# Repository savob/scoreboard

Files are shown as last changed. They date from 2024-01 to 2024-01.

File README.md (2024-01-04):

# Tools 102 Scoreboard

Scoreboard I made for the Tools 102 workshop in 2019. The goal was to bring in some electronics for people to learn with rather than just the usual mechanical stuff done. To that end I wanted to help build an electric countdown system based around an Arduino Nano which would show the time and keep track of score.

# Hardware

For this project I made the main board and a friend did the auxiliary detector board, both were designed to make the most of the back layer since these boards were going to be milled on campus, not etched in a factory. Thus there would be no plated through holes so keeping everything on the back made soldering and connections easier.

The boards were originally designed in EAGLE, but have since been converted to KiCad 7.0.10.

# Software

The code focused on the display function, and was all written in the Arduino IDE 1.8.13.

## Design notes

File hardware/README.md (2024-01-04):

# Hardware

Both these boards were made in EAGLE, but are now in KiCad (7.0.10) format. 

`detector` was meant to pickup a ball passing over a switch and make a single pulse using a 555 timer in monostable mode. A friend made this board.

`timeboard` was meant to be the main board for the system which would actually keep track of the score and display information like time remaining on the display for players to see.

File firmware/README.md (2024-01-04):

# Firmware

The firmware here is for the main board and ran on an Arduino Nano programmed using the Arduino IDE, version 1.8.13 when I wrote this.

Although this was meant to show the time remaining and ring the buzzer at completion, I only ended up focusing in on the display functionality since I really wanted to get the seven-segment to work nicely without any flickering as it was multiplexed digit by digit. I managed this in the second version by using hardware registers in the ATmega to control the outputs rather than the repeated and time-consuming `digitalWrite()` calls.

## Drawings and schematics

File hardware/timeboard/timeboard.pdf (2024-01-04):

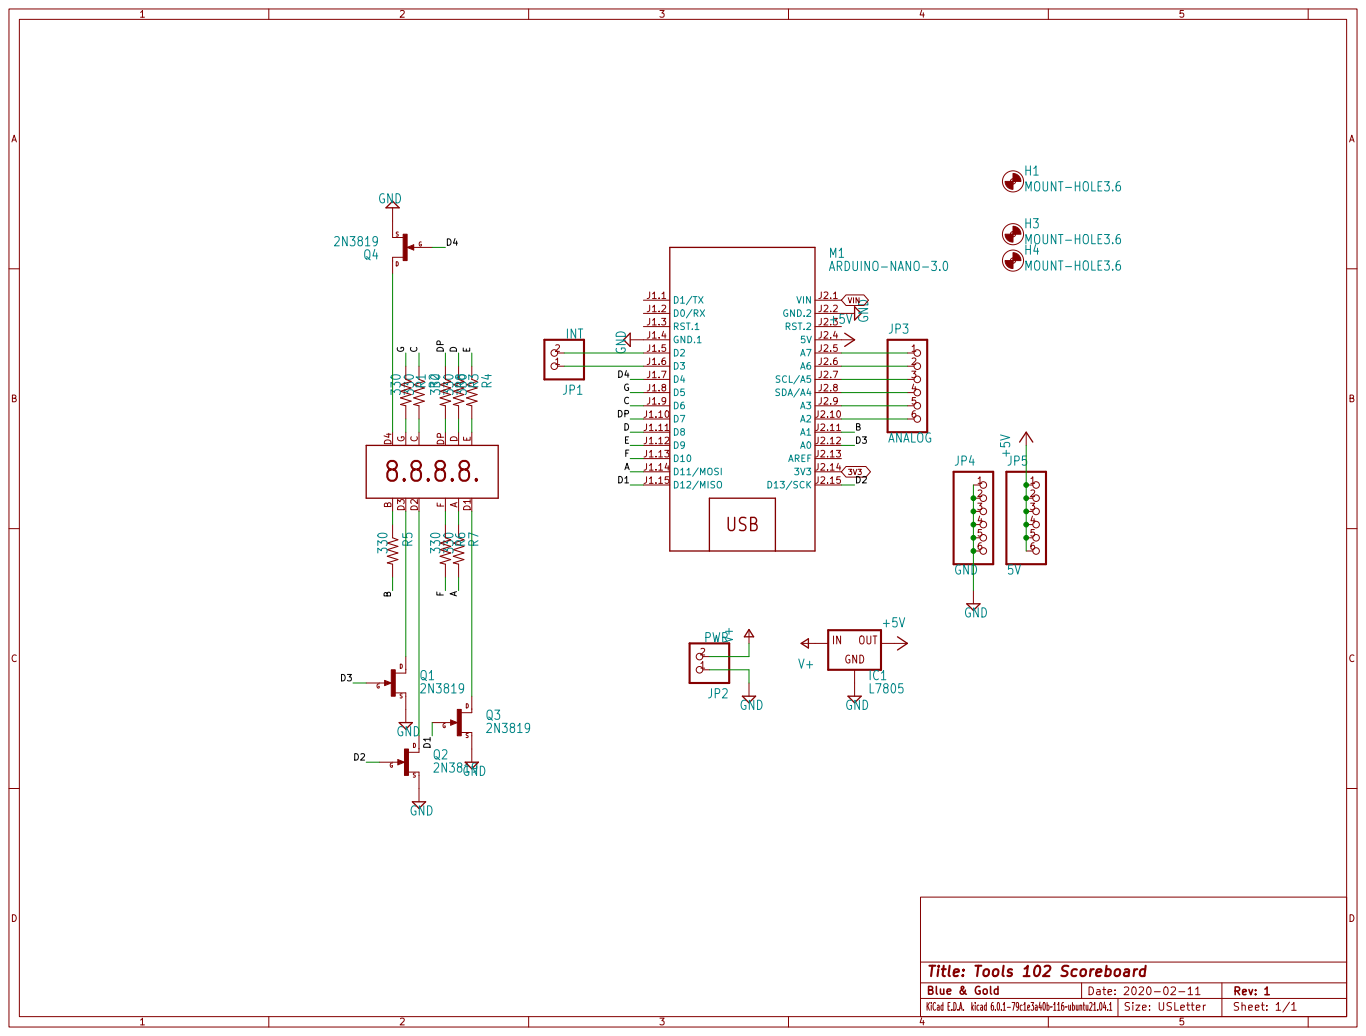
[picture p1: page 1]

Blue & Gold KiCad E.D.A. kicad 6.0.1-79c1e3a40b~116~ubuntu21.04.1 USB

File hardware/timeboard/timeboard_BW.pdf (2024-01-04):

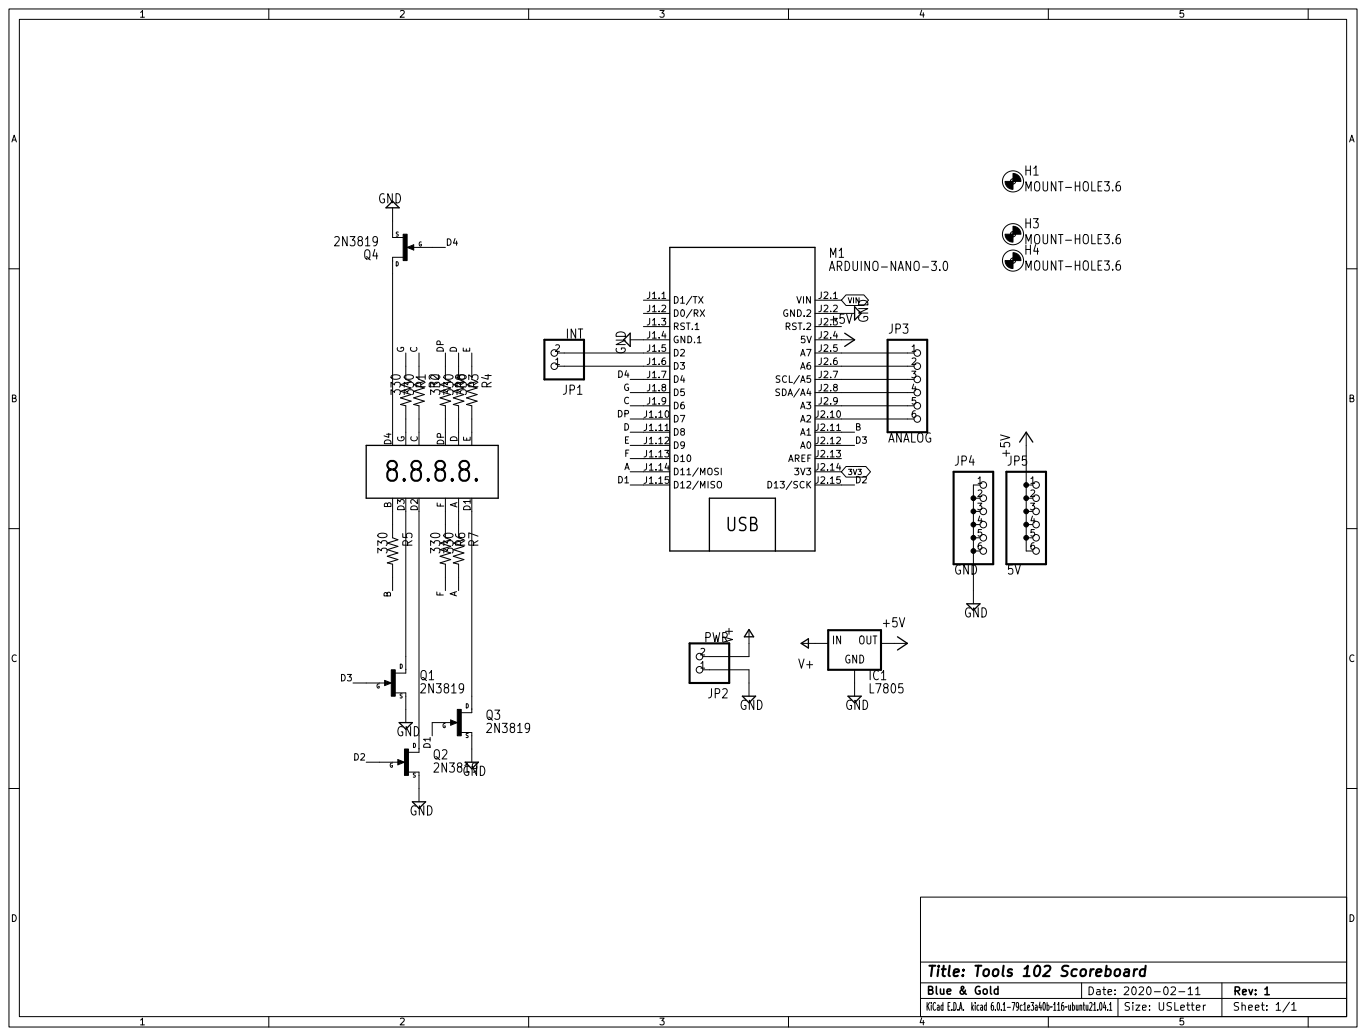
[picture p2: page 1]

Blue & Gold KiCad E.D.A. kicad 6.0.1-79c1e3a40b~116~ubuntu21.04.1 USB

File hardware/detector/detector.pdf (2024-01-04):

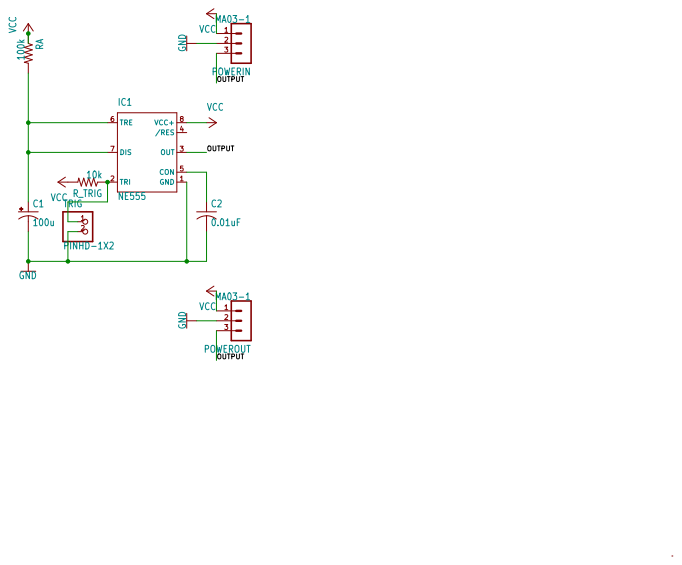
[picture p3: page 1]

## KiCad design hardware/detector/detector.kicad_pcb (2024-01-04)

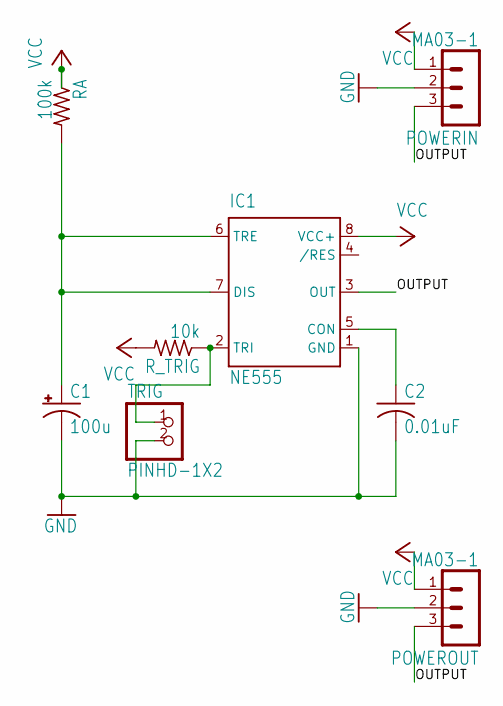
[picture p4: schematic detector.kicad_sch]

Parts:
C1: 100u; E3,5-8
C2: 0.01uF; C050-024X044
IC1: NE555; DIL-08
POWERIN: MA03-1
POWEROUT: MA03-1
RA: 100k; 0207_12
R_TRIG: 10k; 0207_12
TRIG: PINHD-1X2; 1X02

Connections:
GND: C1.-, C2.2, IC1.1 (GND), POWERIN.2, POWEROUT.2, TRIG.2
unnamed: C1.+, IC1.6 (TRE), IC1.7 (DIS), RA.2
unnamed: C2.1, IC1.5 (CON)
unnamed: IC1.2 (TRI), R_TRIG.1, TRIG.1
OUTPUT: IC1.3 (OUT), POWERIN.3, POWEROUT.3
VCC: IC1.8 (VCC+), POWERIN.1, POWEROUT.1, RA.1, R_TRIG.2

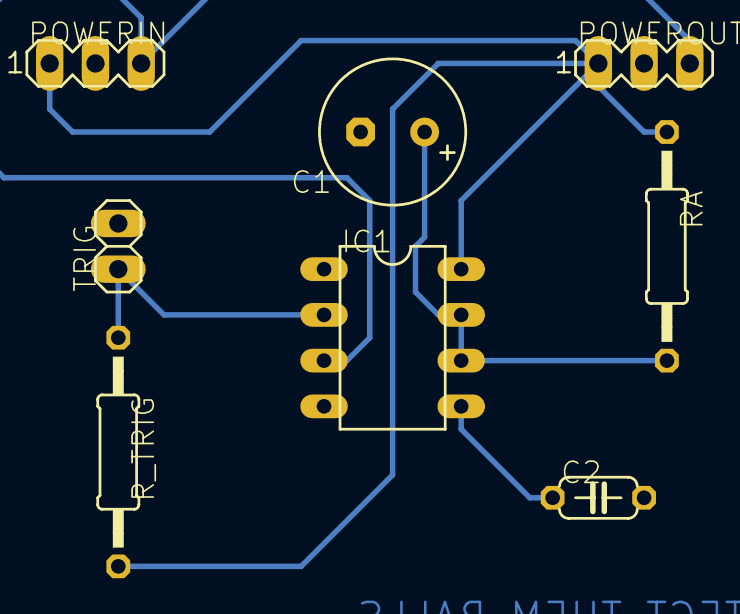
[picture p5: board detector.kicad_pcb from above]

Board: 2 copper layers, 12 parts (0 on the bottom side), 6 nets.

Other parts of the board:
@HOLE0, @HOLE1, @HOLE2, @HOLE3: (no value)

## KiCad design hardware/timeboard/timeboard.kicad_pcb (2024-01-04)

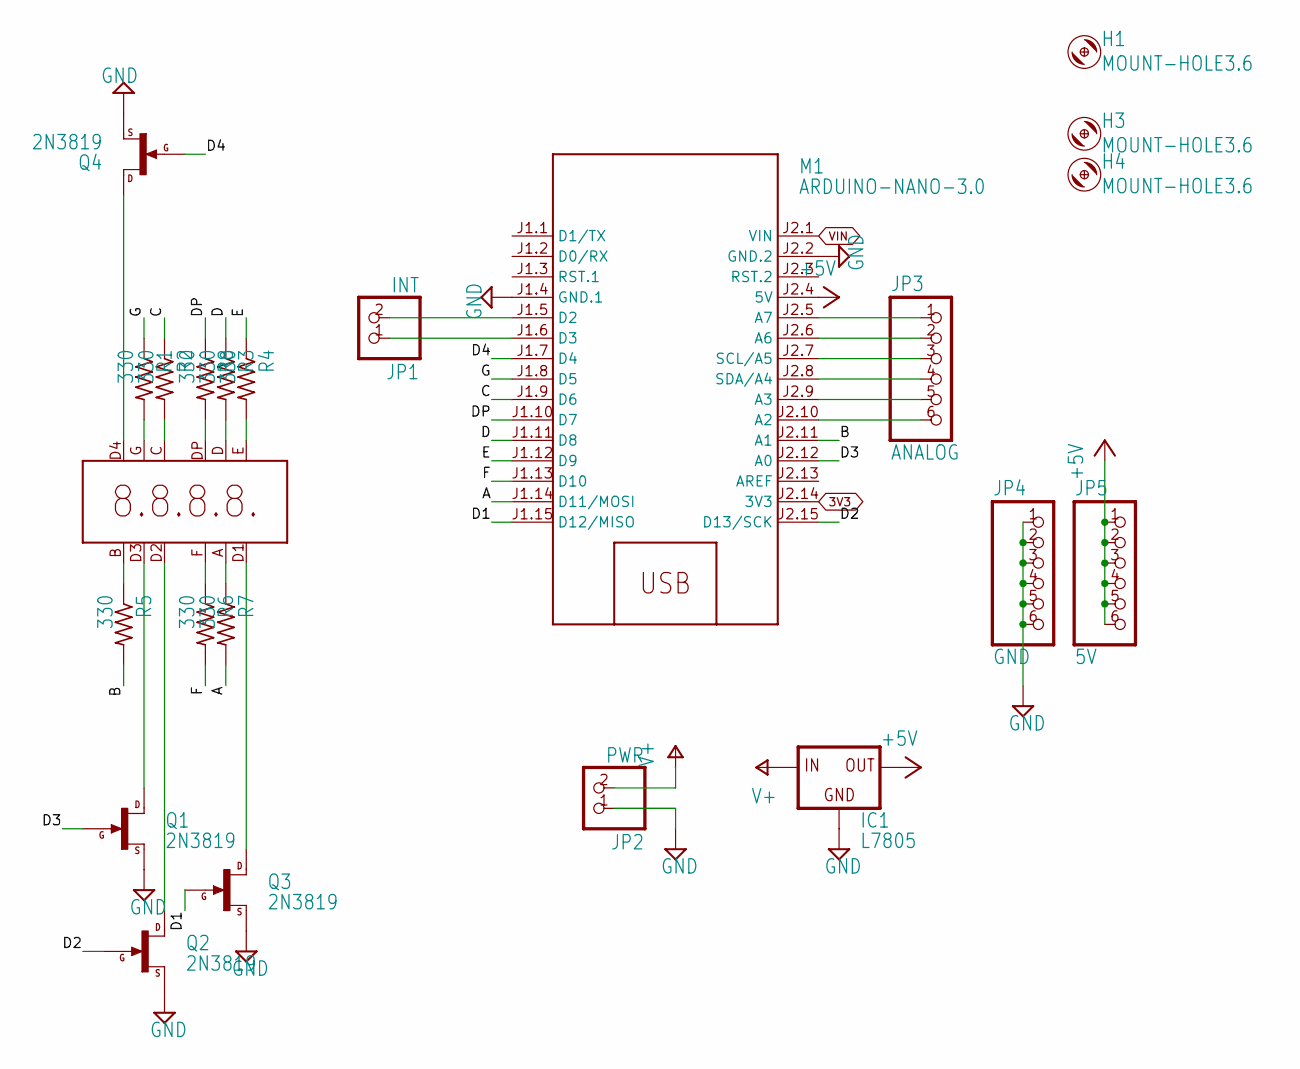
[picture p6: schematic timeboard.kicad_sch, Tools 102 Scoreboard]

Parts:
H1, H3, H4: MOUNT-HOLE3.6; 3,6
IC1: L7805; 78XXS
JP1: INT; 1X02
JP2: PWR; 1X02
JP3: ANALOG; 1X06
JP4: GND; 1X06
JP5: 5V; 1X06
LED1: 7SEG20MM
M1: ARDUINO-NANO-3.0
Q1, Q2, Q3, Q4: 2N3819; TO92F
R1, R2, R3, R4, R5, R6, R7, R8: 330; 0204_5

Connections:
3V3: M1.J2.14 (3V3)
+5V: IC1.OUT, JP5.1, JP5.2, JP5.3, JP5.4, JP5.5, JP5.6, M1.J2.4 (5V)
A: M1.J1.14 (D11/MOSI), R7.2
B: M1.J2.11 (A1), R5.2
C: M1.J1.9 (D6), R2.1
D: M1.J1.11 (D8), R3.1
D1: M1.J1.15 (D12/MISO), Q3.G
D2: M1.J2.15 (D13/SCK), Q2.G
D3: M1.J2.12 (A0), Q1.G
D4: M1.J1.7 (D4), Q4.G
DP: M1.J1.10 (D7), R8.1
E: M1.J1.12 (D9), R4.1
F: M1.J1.13 (D10), R6.2
G: M1.J1.8 (D5), R1.1
GND: IC1.GND, JP2.1, JP4.1, JP4.2, JP4.3, JP4.4, JP4.5, JP4.6, M1.J1.4 (GND.1), M1.J2.2 (GND.2), Q1.S, Q2.S, Q3.S, Q4.S
unnamed: LED1.D4, Q4.D
unnamed: LED1.G, R1.2
unnamed: LED1.C, R2.2
unnamed: LED1.D, R3.2
unnamed: LED1.E, R4.2
unnamed: LED1.DP, R8.2
unnamed: LED1.F, R6.1
unnamed: LED1.A, R7.1
unnamed: LED1.B, R5.1
unnamed: LED1.D3, Q1.D
unnamed: LED1.D2, Q2.D
unnamed: LED1.D1, Q3.D
unnamed: JP1.1, M1.J1.6 (D3)
unnamed: JP1.2, M1.J1.5 (D2)
unnamed: JP3.1, M1.J2.5 (A7)
unnamed: JP3.2, M1.J2.6 (A6)
unnamed: JP3.3, M1.J2.7 (SCL/A5)
unnamed: JP3.4, M1.J2.8 (SDA/A4)
unnamed: JP3.5, M1.J2.9 (A3)
unnamed: JP3.6, M1.J2.10 (A2)
V+: IC1.IN, JP2.2
VIN: M1.J2.1 (VIN)

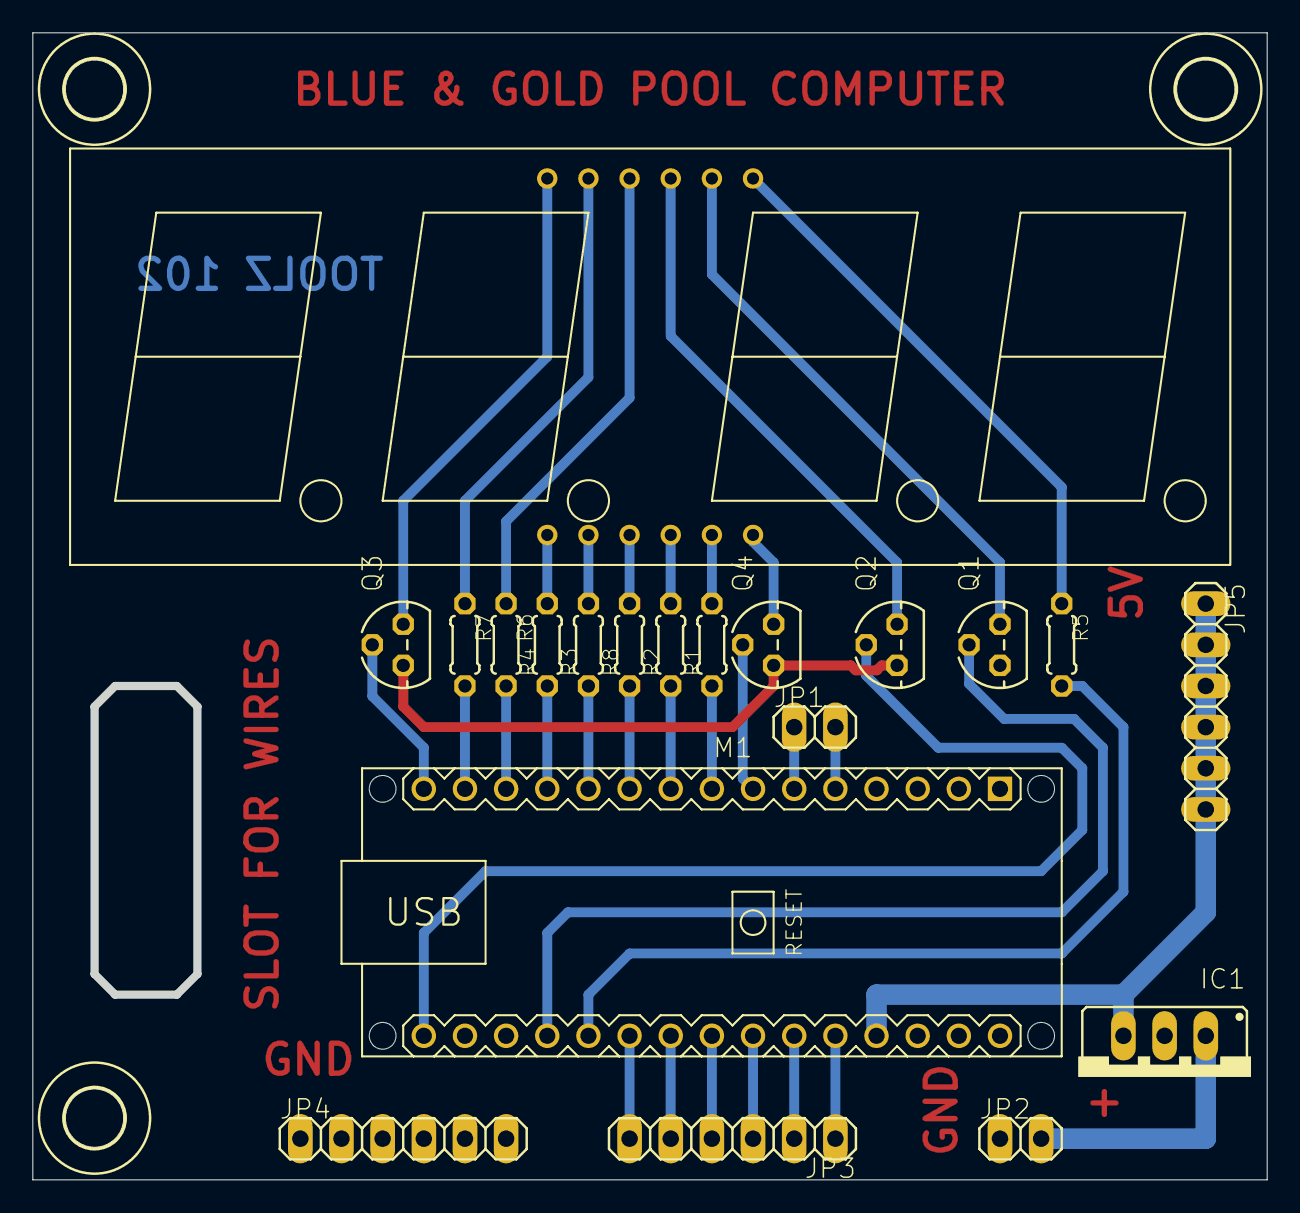
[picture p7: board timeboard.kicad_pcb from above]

Board: 2 copper layers, 76.2 x 70.8 mm, 23 parts (0 on the bottom side), 35 nets.

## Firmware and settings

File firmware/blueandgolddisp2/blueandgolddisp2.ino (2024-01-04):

const byte pinSeg[] = {11, A1, 6, 8, 9, 10, 5, 7}; //A-G,dp
const byte pinDig[] = {12, 13, A0, 4};
const bool digOn = HIGH; // What state to have pins in to turn a digit on
const bool segOn = HIGH; // What state to have pins in to turn on a segment

int displayedChar[4]; // Display buffer
volatile byte currentDigit = 0; // Stores current digit for use in timer interrupt

/* Segment labels
     -A-
    F   B
     -G-
    E   C
     -D- (dp)

   Characters are described in bytes in segment form A to G + DP, lsb to msb
*/
const byte charCount = 20;
byte characterList[charCount] = {B00111111, B00000110, B01011011, B01001111, B01100110, B01101101, B01111101, B00000111, B01111111, B01101111};

// Masks are used to reset all segment and digit pins on each port but not other pins
byte portBClearMask, portCClearMask, portDClearMask;
// These store how to set pins for all characters on a port
byte portBSeg[charCount]; byte portCSeg[charCount]; byte portDSeg[charCount];
// Stores how to set pins in for each digit
byte portBDig[4]; byte portCDig[4]; byte portDDig[4];


void setup() {
  // put your setup code here, to run once:
  Serial.begin(115200);

  for (int i = 0; i < 4; i++) {
    pinMode(pinDig[i], OUTPUT);
  }
  for (int i = 0; i < 8; i++) {
    pinMode(pinSeg[i], OUTPUT);
  }

  // Set timer2 interrupt
  TCCR2A = 0;
  TCCR2B = 0;
  TCNT2  = 0;

  // set compare match register for 500hz increments
  OCR2A = 90; // = (16*10^6) / (1024 * freq) - 1 (must be <256)
  TCCR2A |= (1 << WGM21);   // turn on CTC mode (Clears on timer compare)

  TCCR2B |= (B111 << CS20);   // Set CS20 and CS22 bit for 128 prescaler
  TIMSK2 |= (1 << OCIE2A); // enable timer compare interrupt


  // Adds decimals to numbers array by appending it with the digit with decimal
  // E.g. characterList[1] is the chartacter for 1, characterList[11] is 1 with a deciaml point
  for (byte i = 0; i < 10; i ++) characterList[10 + i] = characterList[i] | B10000000;
  
  // Preparing the lookup tables
  // Messing around with numbers
  setupPortLUT(); // Set up look up table

  //  // LUT Printing for debugging
  //  Serial.println(portBClearMask, BIN);
  //  Serial.println(portCClearMask, BIN);
  //  Serial.println(portDClearMask, BIN);
  //
  //  for (byte i = 0; i < 10; i++) {
  //    Serial.println(i);
  //    Serial.println(portBSeg[i], BIN);
  //    Serial.println(portCSeg[i], BIN);
  //    Serial.println(portDSeg[i], BIN);
  //  }

  Serial.println("GO!");
}

void loop() {
  // Shift characters into buffer
  if (Serial.available()) {
    delay(10);
    int temp = Serial.parseInt();
    temp %= 10000;
    Serial.println(temp);

    // Break down number by digit, starting at thousands digit.
    int base = 1000;
    for (byte i = 0; i < 4; i++) {
      displayedChar[i] = temp / base;
      temp = temp % base;
      base /= 10;
      //Serial.println(displayedChar[i]);
    }
  }
  delay(100);
}

ISR(TIMER2_COMPA_vect) { // Timer2 interrupt, displays a character on the display
  // Display
  // Turn off all digits and segments
  PORTB &= portBClearMask;
  PORTC &= portCClearMask;
  PORTD &= portDClearMask;

  // Turn on required digit
  PORTB |= portBDig[currentDigit];
  PORTC |= portCDig[currentDigit];
  PORTD |= portDDig[currentDigit];

  // Set segments
  PORTB |= portBSeg[displayedChar[currentDigit]];
  PORTC |= portCSeg[displayedChar[currentDigit]];
  PORTD |= portDSeg[displayedChar[currentDigit]];

  if (currentDigit == 3) currentDigit = 0; //Reset
  else currentDigit++;
}

/* Look Up Table Setting
    to make things run fast I will sacrifice memeory and store the pin settings
    for all three ports require for each character present.

    This will require transforming our straightforward character codes into
    the three seperate bytes for each port with the right bits in the right places
    as well as preparing the masks needed to reset the pins needed.

    This will require plenty of bit shifting, masking, and loops. However all the
    results will be saved so it only needs to be calculated once, saving time down
    the line at the expense of

*/

void setupPortLUT() {
  // Set up the look up tables for the three ports to quickly set the ports

  // Clear reset masks
  // Set to 0xFF since AND is used to clear pins by ANDing pins to reset with a 0
  portBClearMask = 255;
  portCClearMask = 255;
  portDClearMask = 255;

  // Clear segment character values
  for (byte i = 0; i < charCount; i++) {
    portBSeg[i] = 0;
    portCSeg[i] = 0;
    portDSeg[i] = 0;
  }
  // Clear digit values
  for (byte i = 0; i < 4; i++) {
    portBDig[i] = 0;
    portCDig[i] = 0;
    portDDig[i] = 0;
  }

  // Time to set digit masks and values

  for (byte i = 0; i < 4; i++) {
    if (pinDig[i] < 8) {
      // Port D
      portDDig[i] |= digOn << pinDig[i];      // Add pin to pin set
      portDClearMask ^= digOn << pinDig[i];  // Toggle the reset mask where the pin is
    }
    else if (pinDig[i] > 13) {
      // Port C
      portCDig[i] |= digOn << (pinDig[i] - 14);
      portCClearMask ^= digOn << (pinDig[i] - 14);
    }
    else {
      // Port B
      portBDig[i] |= digOn << (pinDig[i] - 8);
      portBClearMask ^= digOn << (pinDig[i] - 8);
    }
  }

  // Time to do the same for the segments
  // Will use nested loops to go through all characters for a segment before going to the next segment
  for (byte i = 0; i < 8; i++) {
    byte pinNumber = 0; // Used to store pin number in port
    
    // Find port
    if (pinSeg[i] < 8) {
      // Port D
      pinNumber = pinSeg[i];
      portSegLUTSetting(pinNumber, i, &portDClearMask, portDSeg);
    }
    else if (pinSeg[i] > 13) {
      // Port C
      pinNumber = pinSeg[i] - 14;
      portSegLUTSetting(pinNumber, i, &portCClearMask, portCSeg);
    }
    else {
      // Port B
      pinNumber = pinSeg[i] - 8;
      portSegLUTSetting(pinNumber, i, &portBClearMask, portBSeg);
    }
  }
}

void portSegLUTSetting(byte pinNumber, byte segment, byte* portMask, byte portCharLUT[]) {
  // pinNumber is pin number for the segment on the arduino
  // Segment is which segment the pin corrisponds to (0 for A, 1 for B, etc.)
  // portMask is a reference to the mask used to reset this pin's port
  // portCharLUT[] is the array used to store the values to set pins for each character

  *portMask ^= segOn << pinNumber; // Set the port's reset mask to include the pin

  byte tempMask = 1 << segment; // A temporary mask to be used to extract the segment digit from base character codes

  for (byte j = 0; j < charCount; j++) {
    // Check if segment is on for that character, then set on or off accordingly
    if ((characterList[j] & tempMask) > 0) portCharLUT[j] |= segOn << pinNumber;
    else portCharLUT[j] |= !segOn << pinNumber;
  }

}

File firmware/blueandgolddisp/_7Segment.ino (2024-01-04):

/*
   Note: there is no error checking/correction for inputs

   This code works with the seven segment display. It assumes
   the pins controlling it are sequential all offset by startPin
   The first seven are the segments as shown below:
             -A-
            F   B
             -G-
            E   C
             -D- (dp)
   The eigth pin is that decimal point, then the four for each
   digit (sequencially), and then the semicolon (digit 5)
*/

byte numbers[20] = {B00111111, B00000110, B01011011, B01001111, B01100110, B01101101, B01111101, B00000111, B01111111, B01101111}; // Numbers in segment form A to G, lsb to msb

void addDecimals() {
  // Adds decimals to numbers array by appending it with the digit with decimal
  // E.g. numbers[1] is the chartacter for 1, numbers[11] is 1 with a deciaml point
  
  for (byte i = 0; i < 10; i ++) numbers[10 + i] = numbers[i] | B10000000;
}

void dispDigit(const byte digit, const byte segments) {

  
  // Set segments
  for (int i = 0; i < 8; i++) {
    digitalWrite(pinSeg[i], bitRead(segments, i) ? segOn : !segOn);
  }

    // Turn off all digits
  for (int i = 0; i < 4; i++) {
    digitalWrite(pinDig[i], !digOn);
  }
  
  // Turn on needed digit
  digitalWrite(pinDig[digit], digOn);
}

byte convertNum(byte number) {
  // Number segment powering
  byte numbers[16] = {B00111111, B00000110, B01011011, B01001111, B01100110, B01101101, B01111101, B00000111, B01111111, B01101111}; // Numbers in segment form A to G, lsb to msb
  return numbers[number];
}
byte convertChar(char target) {
  byte x = 0;
  // Check for number
  if ((target < 58) && (target > 47)) return convertNum(target); // Return number is numeric
  
  target = bitClear(target, 5); // Upper case
  switch (target) {
    case ('A'):
      x = B1110111;
      break;
    case ('B'):
      x = B1111100;
      break;
    case ('C'):
      x = B1011000;
      break;
    case ('D'):
      x = B1011110;
      break;
    case ('E'):
      x = B1111001;
      break;
    case ('F'):
      x = B1110001;
      break;
    case ('H'):
      x = B1110101;
      break;
    case ('I'):
      x = B0000100;
      break;
    case ('J'):
      x = B0011110;
      break;
    case ('K'):
      x = B1110110;
      break;
    case ('L'):
      x = B0111000;
      break;
    case ('N'):
      x = B1010100;
      break;
    case ('O'):
      x = B1011100;
      break;
    case ('P'):
      x = B1110011;
      break;
    case ('Q'):
      x = B1100111;
      break;
    case ('R'):
      x = B1010000;
      break;
    case ('T'):
      x = B1000110;
      break;
    case ('U'):
      x = B0011100;
      break;
    case ('V'):
      x = B0011100;
      break;
    case ('Y'):
      x = B1101110;
      break;
    case ('X'):
      x = B1110110;
      break;
    default:
      x = 0; // Blank
      break;
  }
  return x;
}

void displayChar(byte digit, char input) {
  dispDigit(digit, convertChar(input));
}
